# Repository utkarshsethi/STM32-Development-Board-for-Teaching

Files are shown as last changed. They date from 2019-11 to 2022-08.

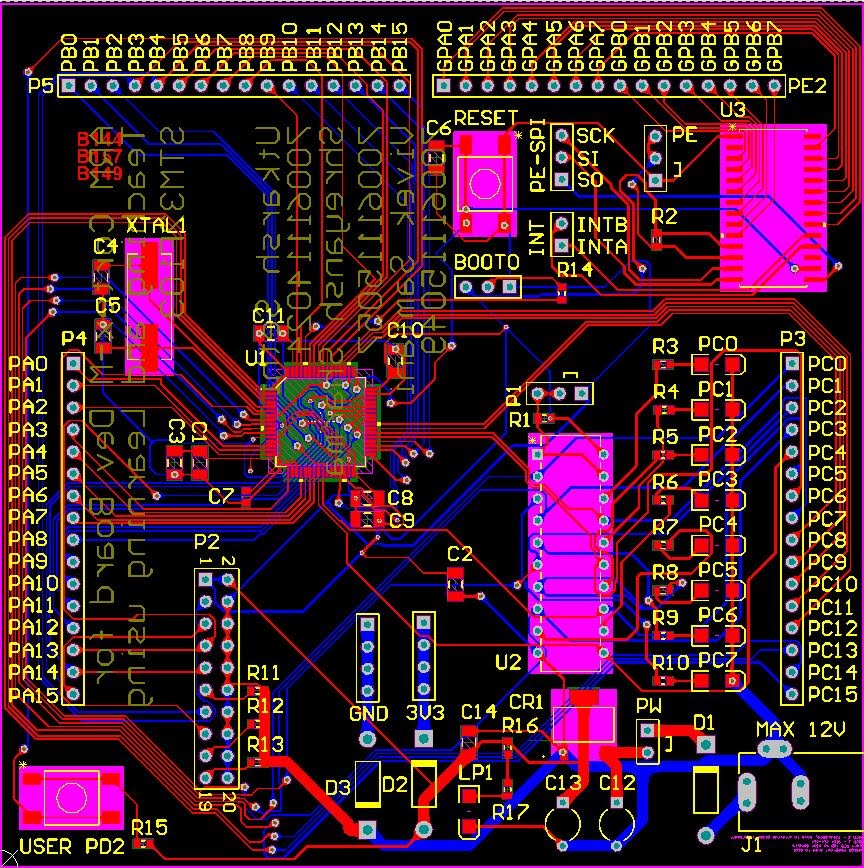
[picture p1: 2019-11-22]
route (1).JPG

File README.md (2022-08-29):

# STM32-Development-Board-for-Teaching 

While studying B Tech 8051 is the controller used in the course syllabus. While 8051 is very fundamental and helpful to understand the basics, it is quite old and not always industry relevant.  It's said to learn something, the best way is to make it. After a lot of exploring I decided what better way to learn ARM is to make a development board. This would expose us to most of the interfaces of the controller while also providing us with exposure to essential skills like schematic design, PCB manufacturing and SMD soldering.  There are a lot of development and evaluation boards but they were not aimed to supplement the uC course at bachelor level, where the students are beginners with none to little experience.  My intention with this board something with separate breakouts for various interfaces like I2C, SPI and also peripherals using those.

https://hackaday.io/project/161177-stm32-development-board-for-teaching

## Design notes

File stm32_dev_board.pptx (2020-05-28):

## STM32 ARM Cortex-M Development Board for Teaching and Prototyping

Presented By:
Utkarsh Sethi
Shreyansh Sharma
Vivek Samtani
Project Supervisors:
1. Prof. Sashikant Patil
2. Prof. Kiran Sanlunkhe
SVKM’s NMIMS, Mukesh Patel School of Technology Management & Engineering

## Outline

- Survey
- Problem Statement
- Proposed Solution/New Features
- Challenges
- Existing controllers
- Outcomes
- Estimated Cost
- Methodology
- Block Diagram
- Timeline
- Bibliography

## Survey

- Feedback from various people working in embedded industry about what they expect from students
- Talked about problems faced by batch mates, juniors as well as seniors about problems faced in understanding microcontrollers
- Feedback from various acquaintances belonging to other colleges including IITs
- 32bit ARM based systems have started costing less compared to 8051 due to mass production and inbuilt peripherals, and reduced time to get it ready
- STM microcontrollers are easily available, and have good documentation, support

## Problem Statement

- The kits used to teach microcontroller in universities gives little exposure to hardware and interfacing
- With lower cost industry is leaning towards ARM over 8bit as it offers standardisation and faster production and lower lead times
- While assembly is important to understand, products is the industry are made using C

## Proposed Solutions/Features

- Arm based boards will make it industry relevant
- Board will be designed in such a way that students also learn hardware and interfacing not just assembly language
- Separate PCBs to understand hardware components required
- Attached sensor and drivers which will not only introduce the interfaces, but also provide hands on experience about how to use the interfaces
- Debugging directly on the hardware will improve understanding

## Challenges

- ARM is complex architecture and will be difficult to introduce to beginners.
- The documentation provided with latest processors is thousands of pages and often cannot be completed in 15labs, so it has to be provided in a concise manner.
- Advanced protocols like usb/Ethernet cannot be covered
- New µCs / ICs cannot be placed on breadboard which make them intimidating

## Existing Products

- 8051 Development board
- ARM Cortex-M3 NXP LPC1768 Development Board
- ARM Cortex-M3 Mini Stm32 Stm32F103ZEt6 Cortex Development Board KG296
- STM32 Nucleo-64 development board with STM32F103RB MCU

## Outcome

Personal :
- To gain in-depth knowledge and understanding about ARM ISA
- Improving essential skills like Schematic, PCB design, SMD Soldering
General :
- Board which helps solve the problem statements
- Can also be later converted into a sellable product

## Estimated Cost

- STM32F103xx: Rs. 250-500
- PCB fabrication: Rs. 1500-2000
- Other peripherals: Rs. 1000-2000
- EstimatedPrice: Rs. 4000-5000

## Methodology

Learn about ARM ISA and Cortex-M specific documentation

Finalise Specifications

Create Schematics

Make PCBs

Ready concise documentation to be provided along the board

## Block Diagram

ADVANCED CONNECTIVITY MODULE
(future)

STM32 CORTEX-M
MICROCONTROLLER

AND BREAKOUT

MINIMUM SYSTEM CONFIG

DAC MODULE
(future)

POWER CIRCUITRY

SWITCHES

ADC MODULE

EXPANSION

MODULE

SWD,JTAG,ST-LINK INTERFACE MODULE

USART MODULE

LCD MODULE

I²C MODULE

GPIO MODULE
(integrated)

PWM MODULEs

SPI MODULE

## Config Diagram

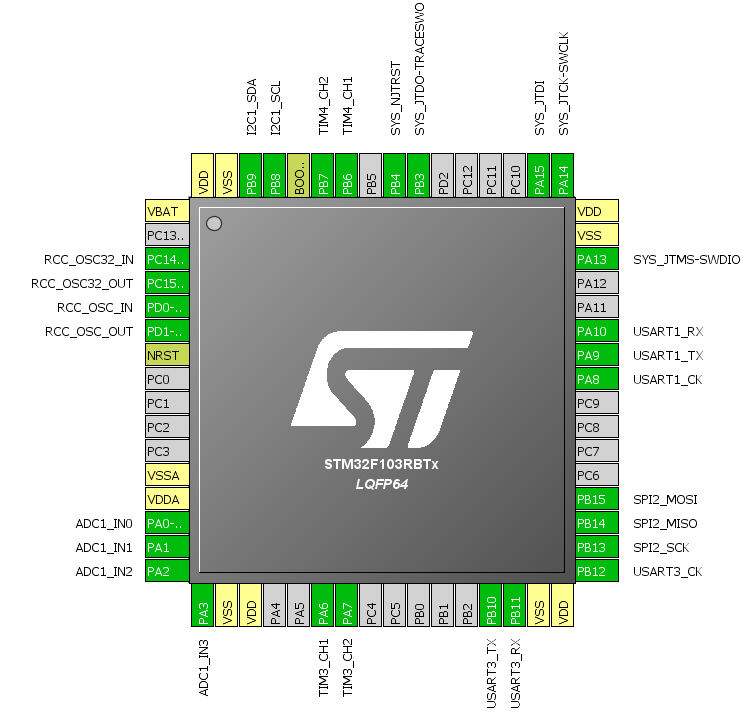
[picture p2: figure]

## Schematic

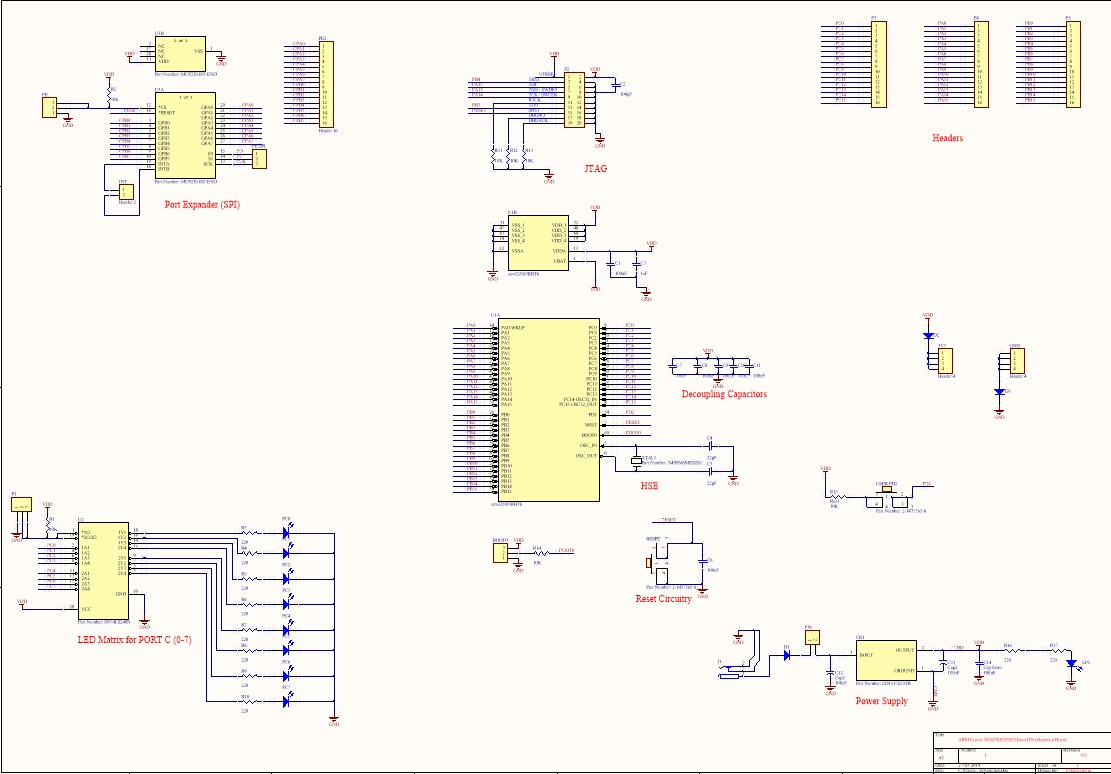
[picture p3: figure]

## Routing

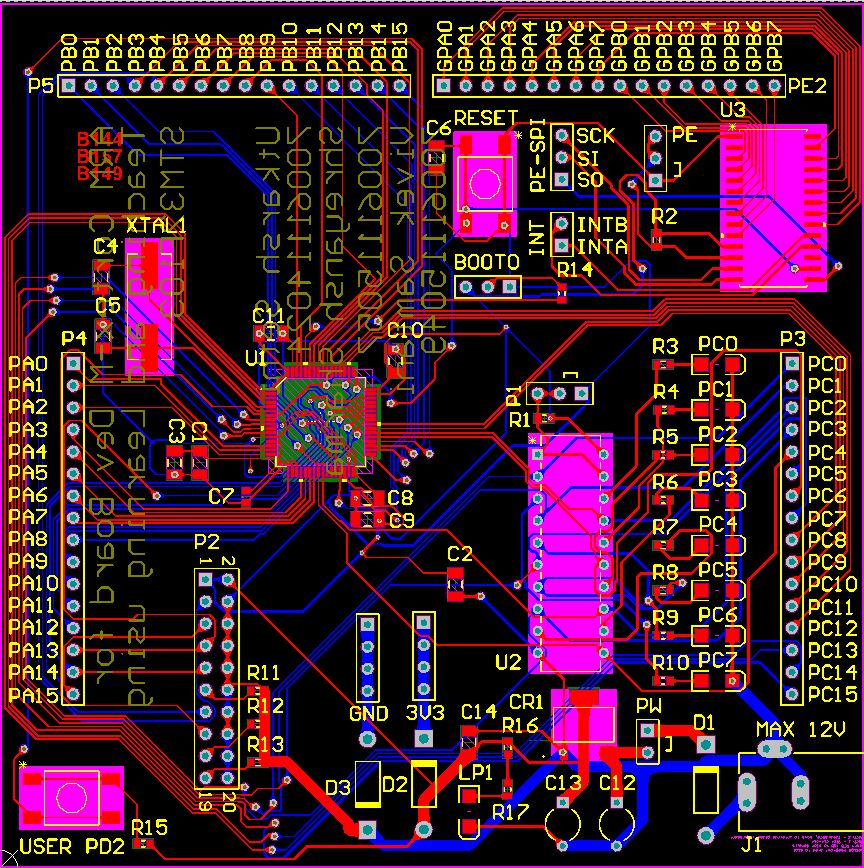
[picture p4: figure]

## Routing

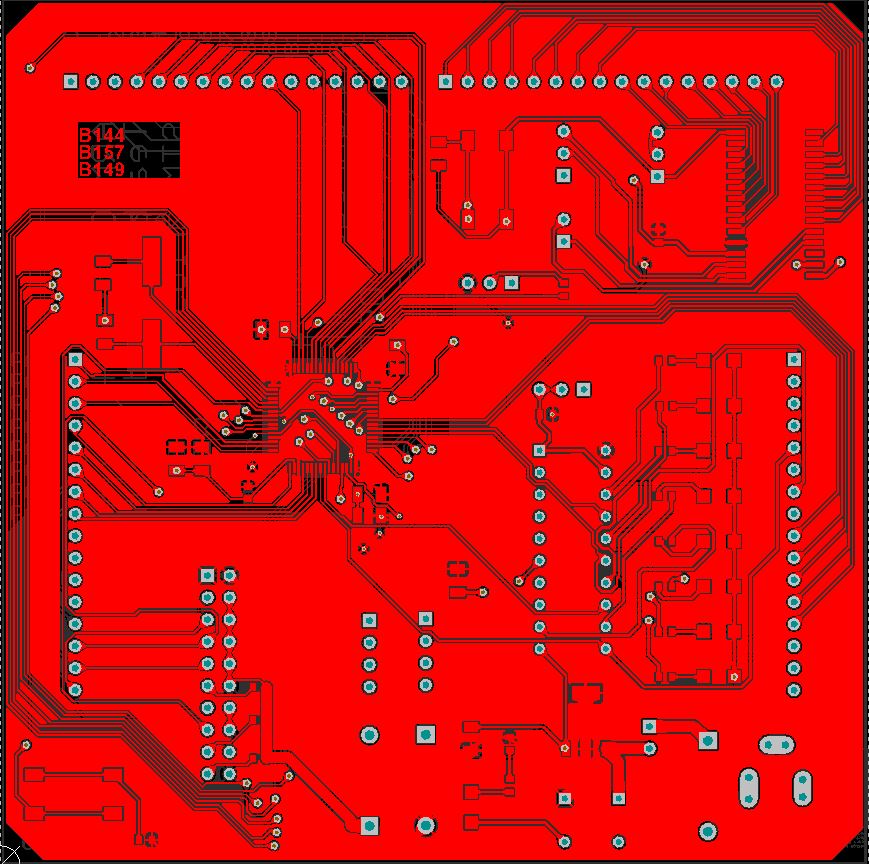
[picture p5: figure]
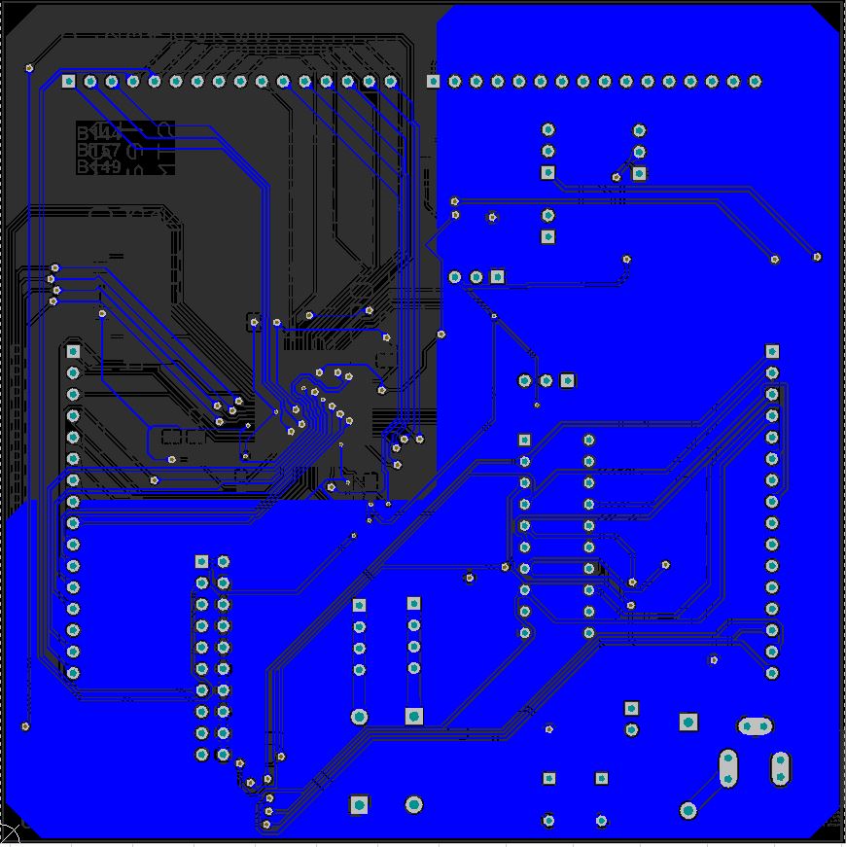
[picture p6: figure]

## 3D Model

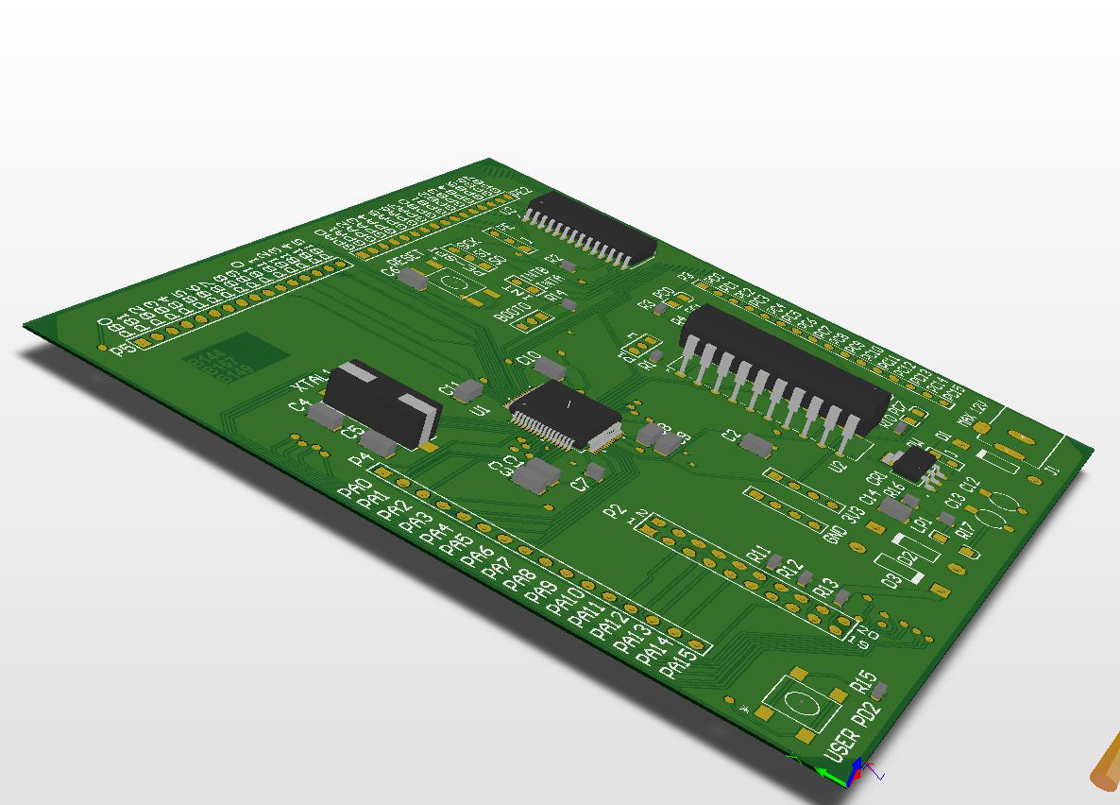
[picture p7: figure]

## Timeline (Sem7)

- Week 1-3 : Discussions
- Week 4-6:Explore the current products
- Week 6-12:Understant the µC and go through documentation, app notes by manufacturer and ARM
- Week 12-13: identify challenges and solutions, features. Finalise µC
- Week 14-15: work on schematics
- Winter Break: work on schematics
- Semester 8 : schematics, further iterations and software + manuals

## Bibliography

1. Whiteway, Alexander Keith . “PIC32 DEVELOPMENT for ECE4760” Electrical and Computer Engineering Projects: Masters of Engineering , May. 2015, people.ece.cornell.edu/land/courses/eceprojectsland (https://people.ece.cornell.edu/land/courses/eceprojectsland/STUDENTPROJ/2014to2015/akw62/akw62_report_201505180311.pdf)/STUDENTPROJ/2014to2015/akw62/akw62_report_201505180311.pdf (https://people.ece.cornell.edu/land/courses/eceprojectsland/STUDENTPROJ/2014to2015/akw62/akw62_report_201505180311.pdf).
2. Ross, Michael David. “PIC32 DEVELOPMENT BOARD.” Electrical and Computer Engineering Projects: Masters of Engineering , Jan. 2014, people.ece.cornell.edu/land/courses/eceprojectsland (https://people.ece.cornell.edu/land/courses/eceprojectsland/STUDENTPROJ/2013to2014/mdr87/mdr87_report_201312201016.pdf)/STUDENTPROJ/2013to2014/mdr87/mdr87_report_201312201016.pdf (https://people.ece.cornell.edu/land/courses/eceprojectsland/STUDENTPROJ/2013to2014/mdr87/mdr87_report_201312201016.pdf).
3. Mahbub , Syed Tahmid Mahbub, “Comparing the PIC32MX250F128B and Atmel AT91SAM3X8E for teaching” Electrical and Computer Engineering Projects: Masters of Engineering , Dec. 2013, people.ece.cornell.edu/land/courses/eceprojectsland (https://people.ece.cornell.edu/land/courses/eceprojectsland/STUDENTPROJ/2013to2014/sm893/Independent%20Study%20Paper%20Final.pdf)/STUDENTPROJ/2013to2014/sm893/Independent%20Study%20Paper%20Final.pdf (https://people.ece.cornell.edu/land/courses/eceprojectsland/STUDENTPROJ/2013to2014/sm893/Independent%20Study%20Paper%20Final.pdf)
4. ST-Microcontrollers, UM0986 User manual, ”Developing your STM32VLDISCOVERY application using the MDK-ARM software ”.
5. ST-Microcontrollers, UM1523 User manual, ” Getting started with software and firmware environments for the STM32F0DISCOVERY kit ”.
6. ST-Microcontrollers, UM1725 User Manual, ” Description of STM32F4 HAL and LL drivers ”.
7. ST-Microcontrollers, AN4488 Application note, ” Getting started with STM32F4xxxx MCU hardware development ”.
8. ST-Microcontrollers, PM0214 Programming manual, ” STM32F3 Series, STM32F4 Series, STM32L4 Series and STM32L4+ Series Cortex®-M4 programming manual ”.
9. ST-Microcontrollers, RM0090 Reference manual, ” STM32F405/415, STM32F407/417, STM32F427/437 and STM32F429/439 advanced Arm®-based 32-bit MCUs ”.
10. ST-Microcontrollers, STM32F405xx STM32F407xx Data Sheet, ” ARM Cortex-M4 32b MCU+FPU, 210DMIPS, up to 1MB Flash/192+4KB RAM, USB OTG HS/FS, Ethernet, 17 TIMs, 3 ADCs, 15 comm. interfaces & camera ”.
11. ST-Microcontrollers, STM32F407VG, https://my.st.com/content/my_st_com/en/products/microcontrollers/stm32-32-bit-arm-cortex-mcus/stm32-high-performance-mcus/stm32f4-series/stm32f407-417/stm32f407vg.ht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 .
12. Various Other Open source Projects related to STM32 and other µCs.

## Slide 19

Thank you

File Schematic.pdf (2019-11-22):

# Headers

# JTAG

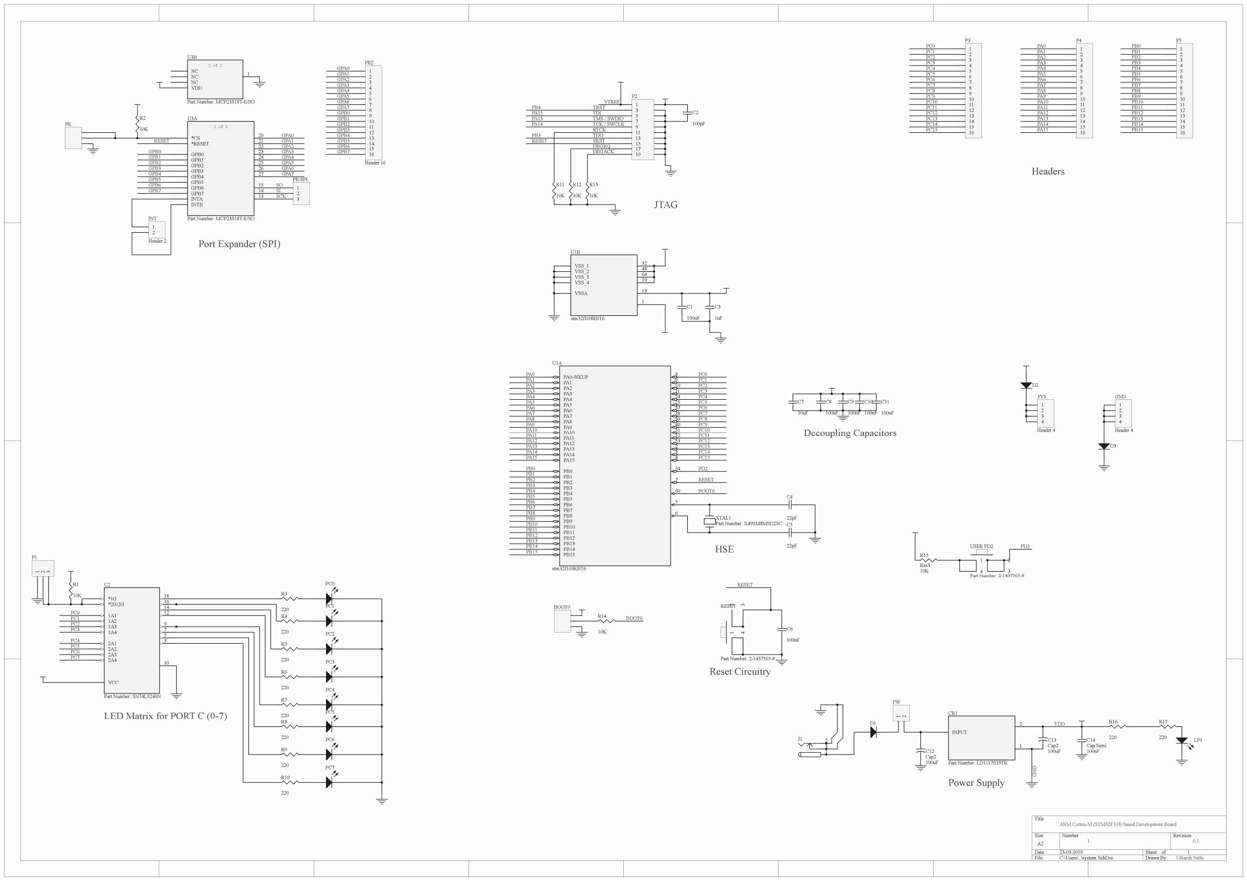
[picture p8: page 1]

Title

Size | Number | Revision
A2
Date: | 23-03-2019 | Sheet of
File: | C:\Users\..\system.SchDoc | Drawn By:

123

J1

100nF

C1

1uF

C3

D1

10uF

C7

100nF

C8

100nF

C9

100nF

C10

100nF

C11 12

PW

100nF

C6

LP1 220

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
# Decoupling Capacitors

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
R10 ¹²³

P1

10K

R1

22pF

C4

22pF

C5

# Port Expander (SPI)

# HSE

# Reset Circuitry

# Power Supply

# LED Matrix for PORT C (0-7)

PE
10K

R2

123

PE-SPI
SO
SI
SCK

INPUT

21

CR1

Part Number: LD1117S33TR

BOOT0

10K

R14

13579

11
13
15
17
19

P2
VTREF
TRST
TDI
TMS / SWDIO
TCK / SWCLK
RTCK
TDO
SRST
DBGRQ
DBGACK

10K

R11

10K

R12

10K

R13

100pF

C2

ARM Cortex-M (STM32F103) based Development Board

1 0.1 1

Utkarsh Sethi ¹ ²3 4

RESET

Part Number: 2-1437565-8

*1G
*2G/2G

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
129753

10

U2

Part Number: SN74LS240N

GPA0
GPA1
GPA2
GPA3
GPA4
GPA5
GPA6
GPA7
GPB0
GPB1
GPB2
GPB3
GPB4
GPB5
GPB6
GPB7

RESET

RESET

BOOT0

PC0
PC1
PC2
PC3

PC4

PC7

PB4
PA15
PA13
PA14

PB3
RESET | GND

VDD

XTAL1
Part Number: X49SM8MSD2SC

*CS
*RESET

GPB0
GPB1
GPB2
GPB3
GPB4
GPB5
GPB6
GPB7
INTA
INTB

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
### 1 of 2

U3A

Part Number: MCP23S18T-E/SO

NC
NC
NC
VDD

1

### 2 of 2

U3B

Part Number: MCP23S18T-E/SO

PA0-WKUP
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
PA10
PA11
PA12
PA13
PA14
PA15

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
PB10
PB11
PB12
PB13
PB14
PB15

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
53234

547

6056

U1A

stm32f103RBT6

VSS_1
VSS_2
VSS_3
VSS_4

VSSA

32
48
64
19

131

U1B

stm32f103RBT6

RESET

BOOT0

123456789

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
123456789

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
123456789

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
PB10
PB11
PB12
PB13
PB14
PB15

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
PA10
PA11
PA12
PA13
PA14
PA15

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
PC10
PC11
PC12
PC13
PC14
PC15

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
PA10
PA11
PA12
PA13
PA14
PA15

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
PB10
PB11
PB12
PB13
PB14
PB15

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
PC10
PC11
PC12
PC13
PC14
PC15

GPB0
GPB1
GPB2
GPB3
GPB4
GPB5
GPB6
GPB7

GPA0
GPA1
GPA2
GPA3
GPA4
GPA5
GPA6
GPA7

123456789

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
Header 16

100nF

C14
Cap Semi

220

R17

12

INT

Header 2

1234

3V3

Header 4

1234

GND

Header 4

1 | 2 4 | 3

USER PD2

Part Number: 2-1437565-8

10K

R15

Res3

PC5
PC6

PD2

PD2

100uF

C12
Cap2

100uF

C13
Cap2

D2

D3

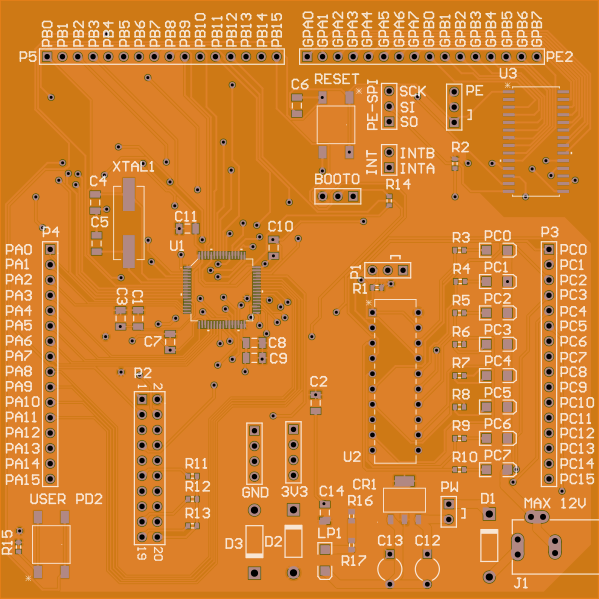
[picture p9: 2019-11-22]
pcb_top.png

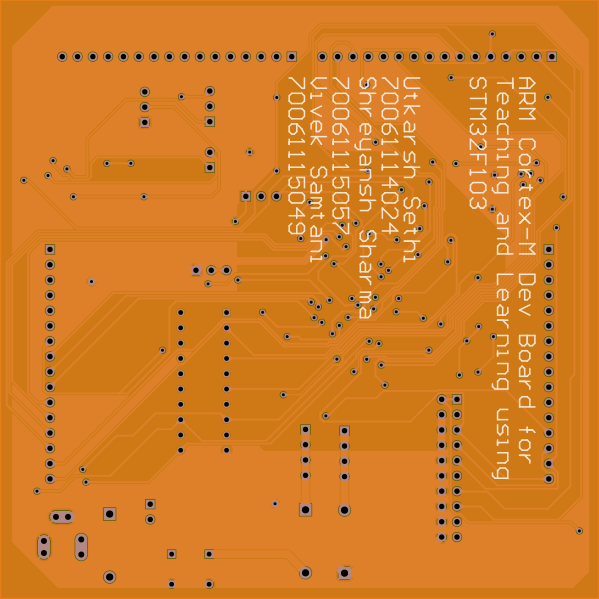
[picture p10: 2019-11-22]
pcb_bottom.png

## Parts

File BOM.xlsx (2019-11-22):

Comment | Description | Designator | Footprint | LibRef | Quantity | Value | Manufacturer_Part_Number | Pins | Layer | PackageDescription
STM32F103RBT6 | STM32F103RBT6 | U1 | LQFP64-10x10mm | STM32F10xRxT2 | 1 |  | STM32F103RBT6 | 64 | Top
Res3 | 10K 5% 0603 SMD Resistor - Royal Ohm 0603SAJ0103T5E | R15 | J1-0603 | Res3 | 1 | 10K | 0603SAJ0103T5E | 2 | Top | Chip Resistor
power on | Yellow Led - SMD (1206 package) | LP1 | 1206 SMD | LED2 | 1 |  | YW-LED-1206 | 2 | Top | 3.2X1.6X1.1
xtal | HC-49SMD 8MHZ 20PF 20PPM 2Pad SMD/SMT Quartz Crystal | XTAL1 | CRYSTAL_TXC_9C | X49SM8MSD2SC | 1 | 8MHZ | X49SM8MSD2SC | 2 | Top
Part Number: SN74LS240N | 74LS240 - Octal Buffers &amp; Line Drivers | U2 | N20 | SN74LS240N | 1 |  | 74LS240 | 20 | Top
Part Number: MCP23S18T-E/SO | MCP23S18-E/SO - 16-bit I/O Port Expander | U3 | SOIC28-W_MC | MCP23S18-E/SO | 1 |  | MCP23S18T-E/SO | 28 | Top
Part Number: LD1117S33TR | NCP1117ST33T3G ON Semiconductor | CR1 | SOT-223 | NCP1117ST33T3G | 1 | 3.3 V FIXED | LD1117S33TR | 3 | Top
FSM2JSMAA=TACTILE 260G FORCE S | Pushbutton (4 pin Tactile-Micro) Switch - Small | RESET, USER PD2 | SW4_FSM-4P44 | 2-1437565-8 | 2 |  | 2-1437565-8 | 4 | Top
pitch = 2.54mm/0.1 | Header, 16-Pin | PE2 | HDR1X16 | Header 16 | 1 |  |  | 16 | Top
pitch = 2.54mm/0.1 | Header, 4-Pin | 3V3, GND | HDR1X4 | Header 4 | 2 |  |  | 4 | Top
pitch = 2.54mm/0.1 | Header, 2-Pin | INT | HDR1X2 | Header 2 | 1 |  |  | 2 | Top
Cap2 | 100uF/50V Electrolytic Capacitor | C12, C13 | CAPR5-4X5 | Cap2 | 2 | 100uF | ELCOS-100/50V | 2 | Top | Capacitor; 2 Leads
Cap Semi | 100 nF 50V 1206 SMD Multi-Layer Ceramic Capacitor - 1206B104K500CT Walsin | C1,c8,c9,c10,c11,c6,c14 | C1206 | Cap Semi | 7 | 100nF |  | 2 | Top | Chip Capacitor
Cap Semi | 10 uF 25V 1206 SMD Multi-Layer Ceramic Capacitor - 1206X106M250CT Walsin | C7 | 0603 | Cap Semi | 1 | 10uF |  | 2 | Top | Chip Capacitor
Cap Semi | 100 pF 50V 1206 SMD Multi-Layer Ceramic Capacitor - 1206N101J500CT Walsin | C2 | C1206 | Cap Semi | 1 | 100pF |  | 2 | Top | Chip Capacitor
Cap Semi | 22 pF 50V 1206 SMD Multi-Layer Ceramic Capacitor - 1206N220J500CT Walsin | C5,C5 | C1206 | Cap Semi | 2 | 22pF |  | 2 | Top | Chip Capacitor
1N4007 | 1N4007 Diode | D1, D2, D3 | DO-41 | 1N4007 | 3 |  |  | 2 | Top | Diode, Axial; Body 5.2 x 2.7 mm (LxDia. max), Lead Dia. 0.86 mm (max)
pitch = 2.54mm/0.1 | Header, 10-Pin, Dual row | P2 | HDR2X10 | Header 10X2 | 1 |  |  | 20 | Top
pitch = 2.54mm/0.1 | Header, 16-Pin | P3, P4, P5 | HDR1X16 | Header 16 | 3 |  |  | 16 | Top
pitch = 2.54mm/0.1 | Header, 2-Pin | PW | HDR1X2 | Header 2 | 1 |  |  | 2 | Top
pitch = 2.54mm/0.1 | Header, 3-Pin | BOOT0, P1, PE, PE-SPI | HDR1X3 | Header 3 | 4 |  |  | 3 | Top
 | Low Voltage Power Supply Connector DC Connector Female | J1 | KLD-0202 | PWR2.5 | 1 |  | DC-05 | 9 | Top
 | 10K 5% 0603 SMD Resistor - Royal Ohm 0603SAJ0103T5E | R1,R2,R11,R12,R13,R14,R15 | J1-0603 | Res3 | 7 | 10K |  | 2 | Top | Chip Resistor
 | 220E 5% 0603 SMD Resistor - Royal Ohm 0603SAJ0221T5E | R3,R4,R5,R6,R7,R8,R9,R10,R16,R17 | J1-0603 | Res3 | 10 | 220 OHM |  | 2 | Top | Chip Resistor
 | Typical RED, GREEN, AMBER LED SMD (1206 package) | PC0, PC1, PC2, PC3, PC4, PC5, PC6, PC7 | 1206 SMD | LED2 | 8 | ANY | LED-1206 | 2 | Top | 3.2X1.6X1.1

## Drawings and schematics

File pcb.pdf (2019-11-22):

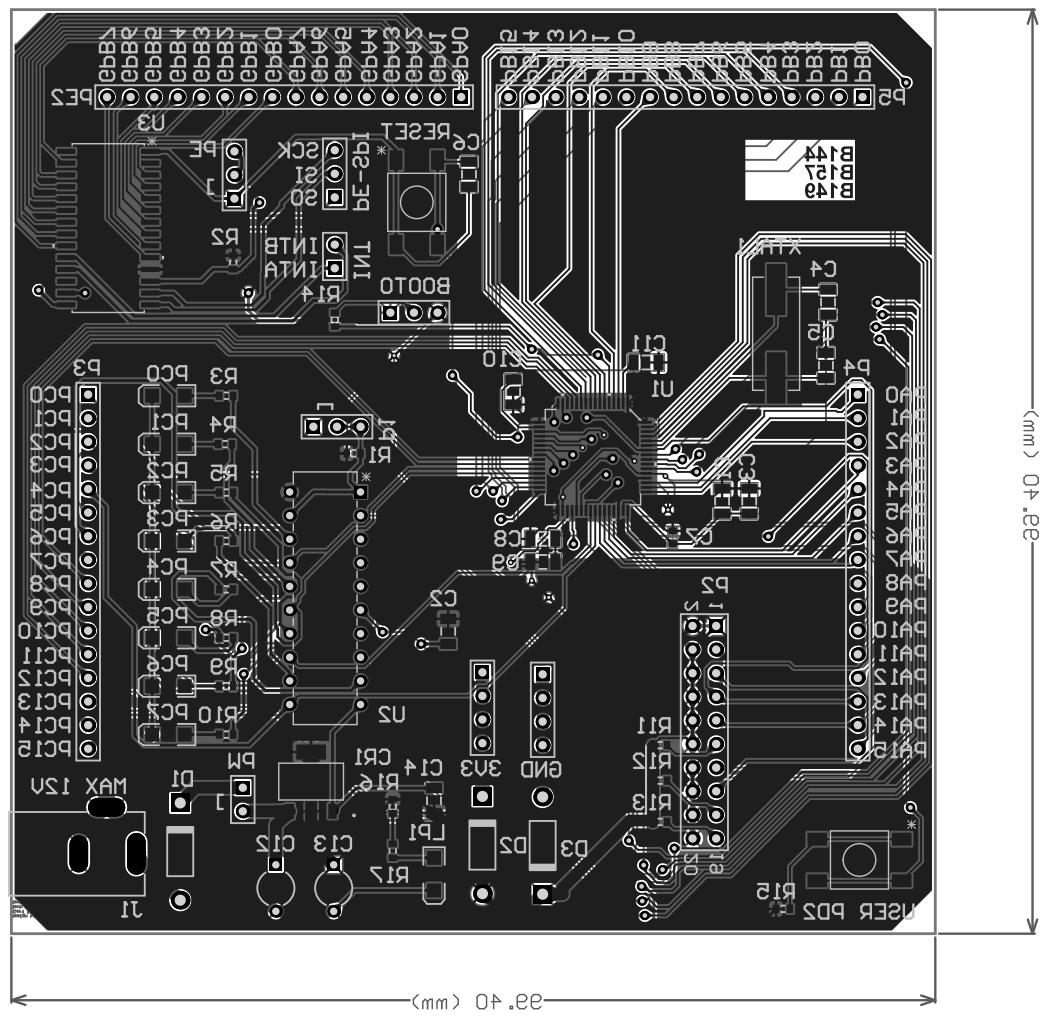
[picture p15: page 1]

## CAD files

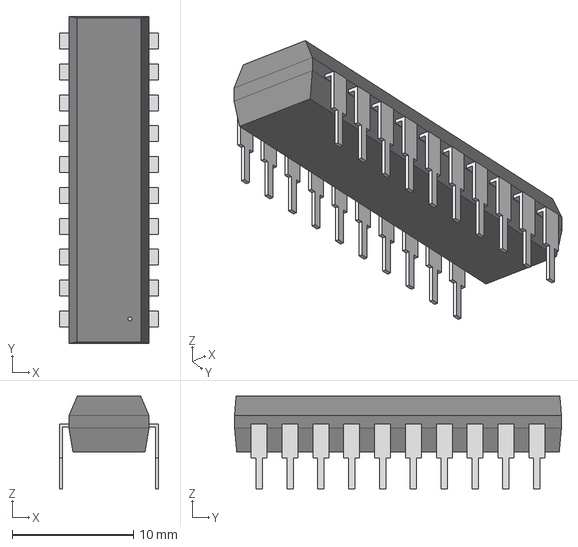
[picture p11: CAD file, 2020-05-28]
CAD/74LS240/74LS240/STEP/N20.step
8.13 x 26.9 x 7.62 mm

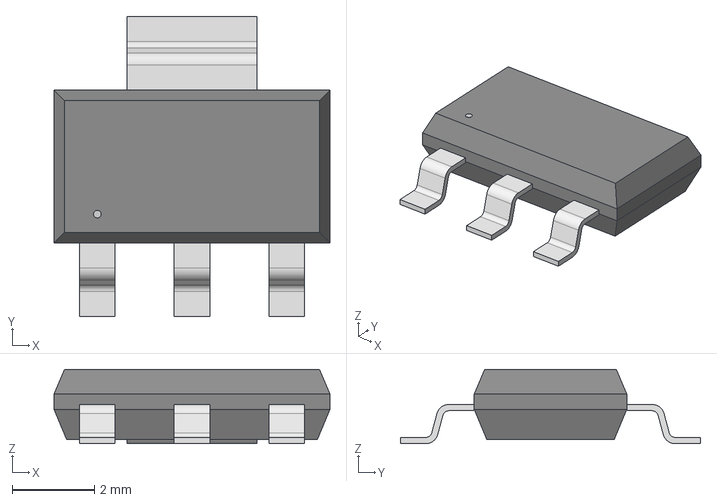
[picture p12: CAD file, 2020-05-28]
CAD/LM1117/LM1117/STEP/SOT-223-M.step
6.71 x 7.29 x 1.81 mm

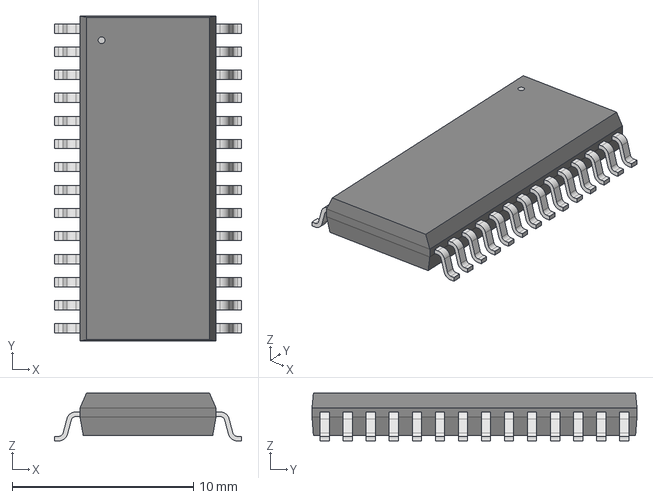
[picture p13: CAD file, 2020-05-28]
CAD/MCP23S17E_SO/MCP23S17E_SO/STEP/SOIC28-W_MC-L.step
10.3 x 17.9 x 2.64 mm

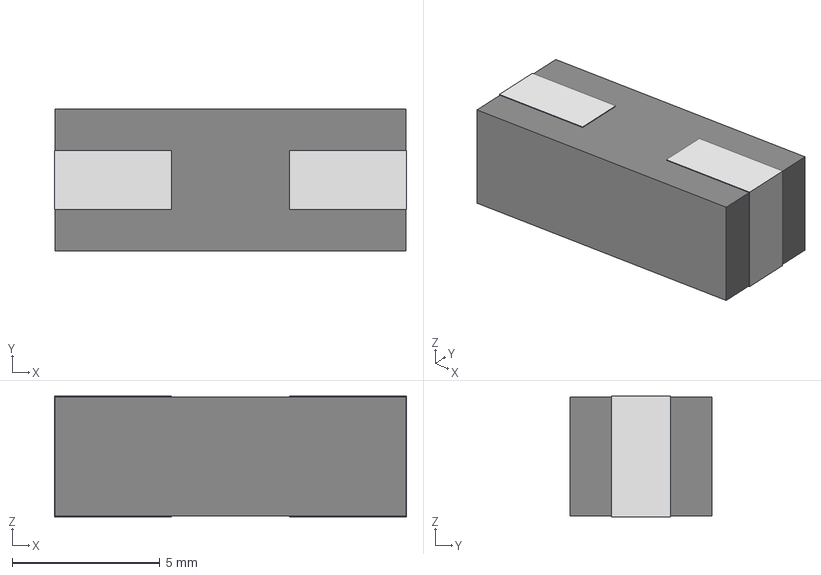
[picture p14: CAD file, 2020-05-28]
CAD/XTAL_SMD/XTAL_SMD/STEP/CRYSTAL_TXC_9C.step
11.9 x 4.80 x 4.09 mm

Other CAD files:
CAD/MCP23S18TESO/STEP/SOIC28-W_MC-L.step
CAD/LM1117/LM1117/STEP/SOT-223-L.step
CAD/MCP23S17E_SO/MCP23S17E_SO/STEP/SOIC28-W_MC.step
CAD/MCP23S18TESO/STEP/SOIC28-W_MC-M.step
CAD/LM1117/LM1117/STEP/SOT-223.step
CAD/MCP23S17E_SO/MCP23S17E_SO/STEP/SOIC28-W_MC-M.step
CAD/MCP23S18TESO/STEP/SOIC28-W_MC.step
